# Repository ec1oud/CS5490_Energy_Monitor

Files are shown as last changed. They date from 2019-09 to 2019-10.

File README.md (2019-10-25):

# UEXT AC Energy Monitor module

I'm developing this for use with an 
[Olimex board](https://www.olimex.com/Products/OLinuXino/RT5350F/RT5350F-OLinuXino-EVB/open-source-hardware)
that runs [OpenWrt](https://openwrt.org/toh/olimex/rt5350f-olinuxino-evb) and
has two GPIO-controlled relays, which I'm hoping to use as a pool pump
controller.  I want to be able to monitor the performance of the pool pump over
time, because this summer it started overheating and eventually failed.  It
would be nice to get an early warning when that's about to happen.  I was
searching and it seems that the 
[CS5490](https://www.cirrus.com/products/cs5490/) will fit the bill: it's 3.3V
powered, cheap enough, doesn't require much supporting circuitry, and works
with current transformers.  The little Olimex board ought to be a good
replacement for the old PC with a DS2413 relay connected to a DS9490 USB
adapter, that has been acting as a pool pump timer (and doing some other minor
home automation tasks) for a few years.

So far I have a working breakout board, designed with 
[KiCad](http://kicad-pcb.org/), that is successfully measuring AC current.  It
has a resistive voltage divider for measuring voltage too, but there is a
safety issue: the design requires connecting DC ground to the neutral wire,
while the other end of the voltage divider goes to line voltage.  Usually
embedded systems like this are kept "floating" behind a transformer or isolated
switching power supply.  I would prefer to measure the full 240VAC that the
pool pump runs on, for accurate power computation, but of course I'm not going
to connect the DC ground of this board (and consequently the ground of the
Olimex board) to a "hot" wire.  In either case, the isolation of the Ethernet
port would depend on the fact that (hopefully) the network jack is
transformer-coupled, because I certainly wouldn't want to cause ground loop
issues on the network either.

Measuring current might be good enough to monitor my pool pump (although it's
not satisfying not to get all the measurements this chip is capable of).  But
to really use it as an energy monitor for anything other than 120VAC US-type
circuits, an isolated design is needed.  I'm thinking my options are to let the
entire CS5490 chip run from an independent power supply and use optocouplers to
isolate the serial line, so that the Olimex board can have a floating DC
ground; or, run everything from a plain old step-down transformer, measure the
AC voltage coming from the transformer (before the rectifier), and calibrate
the CS5490 so that it thinks it's measuring the full AC voltage feeding the
transformer.  An AC brownout ought to result in a proportionately lower voltage
from the transformer; and I hope there is no phase difference significant
enough to affect the power computation.

It also turns out the RT5350F-OLinuXino-EVB has a design flaw: the 
[UEXT connector](https://www.olimex.com/Products/Modules/UEXT/) has a serial
port, but it's the same one that the OpenWrt firmware is using for the Linux
console!  So I can't use those serial lines for communicating with external
hardware (which I thought is supposed to be the main purpose of a UEXT
connector) unless I alter the firmware (or at least the kernel boot parameters)
to disable the serial console, which would also amount to "bricking" the board
if anything goes wrong with the network configuration.  But there's another
serial port on the 40-pin EXT4 connector.  So I designed my board to plug into
the UEXT connector, but now I need to redesign it to plug into the 40-pin
connector instead, which makes it less portable to other embedded systems.  And
also take care of the AC isolation problem somehow.

So now you know the caveats... you'd probably better not connect the line and
neutral screw terminals to anything, unless you know what you're doing.  But
measuring current with a current transformer is pretty safe AFAIK, and works
fine with this design.  I wrote a little test GUI with Qt to communicate with
the board using an FTDI adapter or something like that.  I also wrote another
test client using Lua 5.1 on the OpenWrt firmware, but it depends on being able
to use lua-rs232 at 600 baud (the default baud rate of the CS5490's serial
lines).  See 
[the issue about that](https://github.com/openwrt/packages/issues/10024).

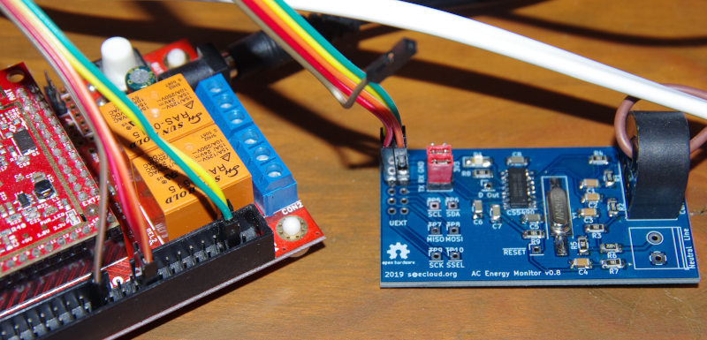
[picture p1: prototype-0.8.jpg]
photo of the prototype so far


A design for a 3D-printable DIN rail mounting solution is also included:

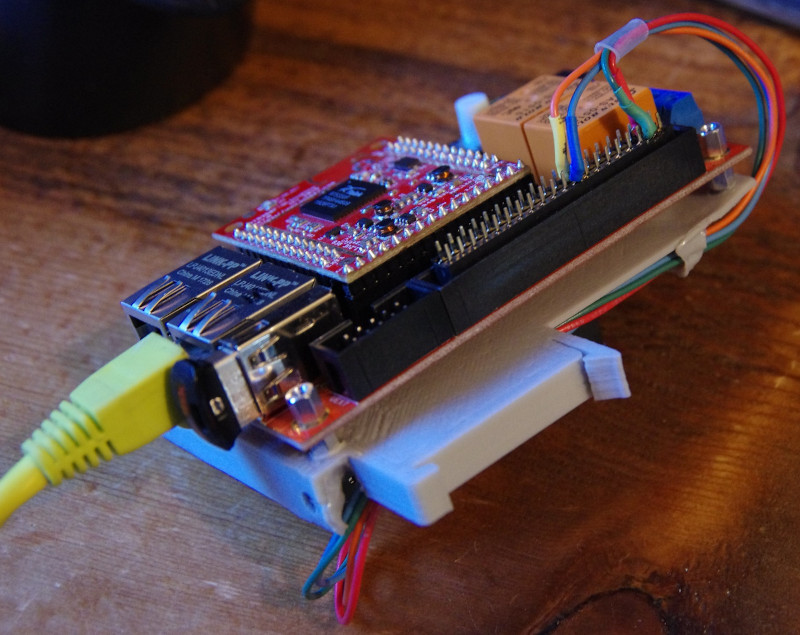
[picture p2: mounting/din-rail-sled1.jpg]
sled for mounting on a DIN rail


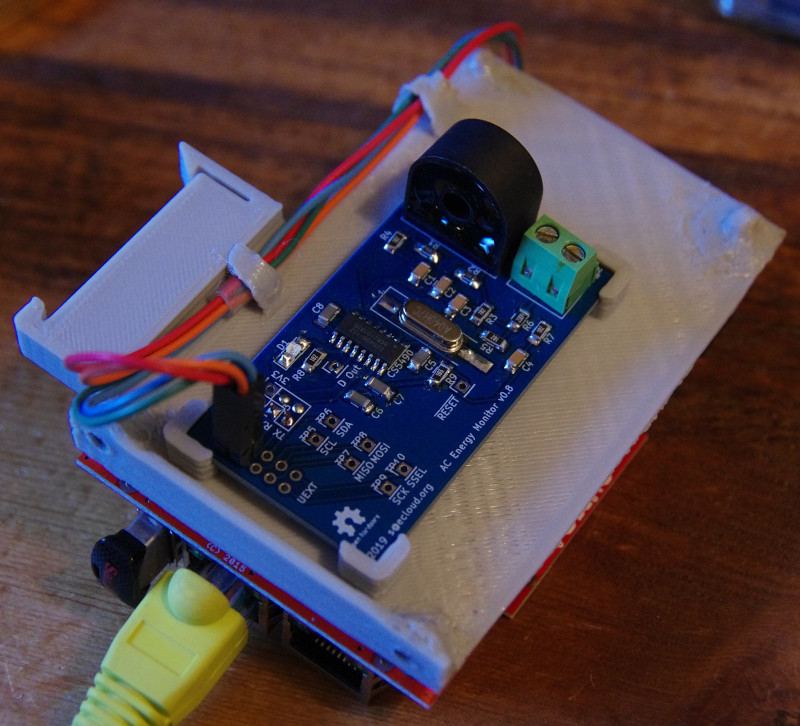
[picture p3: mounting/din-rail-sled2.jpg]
sled for mounting on a DIN rail


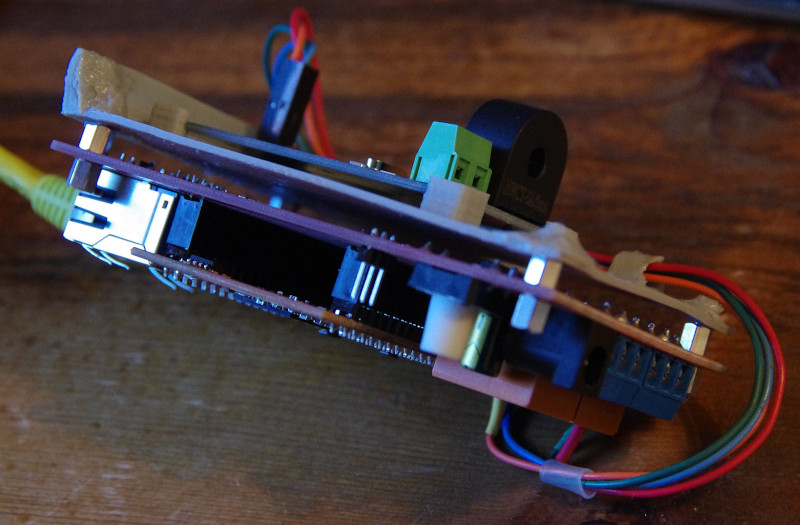
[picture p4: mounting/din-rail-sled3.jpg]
sled for mounting on a DIN rail


The hardware design is licensed under a 


[Creative Commons Attribution-ShareAlike 4.0 International License](http://creativecommons.org/licenses/by-sa/4.0/)
.

The software has a GPLv3 license.

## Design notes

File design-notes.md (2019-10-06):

# Burden Resistors

If one uses a pair of 22Ω resistors for R1 and R2, then for example when
measuring 3.3A RMS with a 1000:1 transformer, the voltage from IIn+ to IIn-
should be 145mV RMS: V = IR, 3.3 / 1000 * 44 = 0.1452.  I measured 140mV with
my voltmeter under such conditions.  The full-scale range is up to 250mV, or
176.78 mV RMS: so with these burden resistors, we won't be able to measure much
more current than that.

So to be able to measure up to 30A for example, it seems the burden resistors
should be 8Ω total, therefore 4Ω each; then 250mV corresponds to 31.25A.  If we
use 3.3Ω instead, we should be able to measure 37.88A peak or 26.78A RMS.

But the CS5490's RMS current register (page 16 address 6) has a range of 0 to
1; so we'll need to calibrate it for a different current range and multiply the
output in the client software.

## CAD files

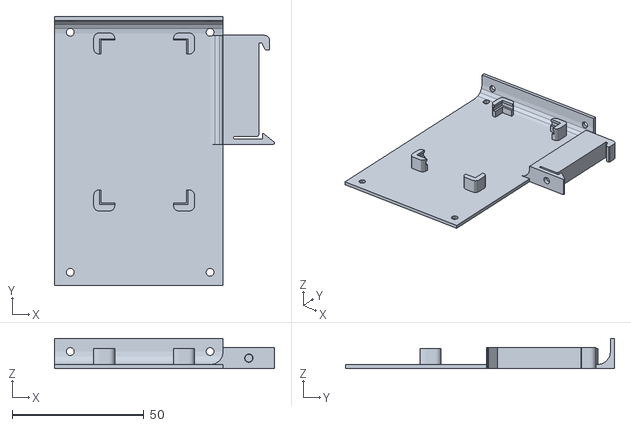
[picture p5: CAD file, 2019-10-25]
mounting/olimex-RT5350F-OLinuXino-EVB-and-CS5490-din-rail-sled.stl
83.5 x 102.0 x 11.5

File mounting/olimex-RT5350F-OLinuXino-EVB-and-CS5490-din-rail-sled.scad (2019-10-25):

// This work is licensed under a Creative Commons Attribution-ShareAlike 3.0 Unported License.
// https://creativecommons.org/licenses/by-sa/3.0/

// board dimensions
boardLength = 102;
boardWidth = 64;
// holes in board
boardWidthStandoffSpacing = 53;
boardHeightStandoffSpacing = 91;

board2dims = [34.25, 63.5, 2];

// DIN rail clamp thickness
clampThickness = 8;
// thickness of sled for board
sledThickness = 1.5;
// the top of the row of PowerPoles will be this far above the DIN rail
heightAboveRail = 10;
// how deep the bolt should go into the solid part, past the spring clip
boltHoleDepth = 10;
// diameter where the bolt passes through the spring clip
looseBoltDiameter = 3.2;
// diameter where the bolt should screw into the DIN holder body
tightBoltDiameter = 2.9;
// standoff dims
standoffDiameter = 8;
standoffScrewHoleDiameter = 3;
standoffHeight = 2.5;

$fn = 16;

// DIN rail clamp
// adapted from Thingiverse 101024 by Robert Hunt
// made with 1mm wider opening: my rail is bigger or my printer prints too small
// Dimensions: 19.74 x 41.355 x clampThickness
module din_clamp() {
	$fn = 24;
	translate([-9.72, -13.1, 0]) mirror([1, 0, 0])
	difference() {
		linear_extrude(height=clampThickness, convexity=5) {
			// imported Robert's DXF to Inkscape, adjusted, then exported via https://github.com/martymcguire/inkscape-openscad-poly
			polygon(points=
				[[-9.731, 16], [5.910, 16], [6.675, 15.848], [7.324, 15.415], [7.758, 14.766], [7.910, 14], [7.910, 10.855],
				[7.764, 10.502], [7.410, 10.355], [6.854, 10.355], [6.320, 10.510], [5.951, 10.925], [4.910, 13.105], [3.910, 13.106],
				[3.910, -21.394], [3.832, -21.783], [3.617, -22.101], [3.299, -22.315], [2.910, -22.394], [-5.372, -22.394], [-5.736, -22.550],
				[-5.852, -22.894], [-5.729, -23.238], [-5.372, -23.394], [5.160, -23.394], [5.160, -21.464], [5.302, -21.239], [5.566, -21.269],
				[9.561, -24.465], [9.730, -24.717], [9.721, -25.021], [9.538, -25.263], [9.249, -25.355], [-9.731, -25.355]]
				, paths=
				[[0, 1, 2, 3, 4, 5, 6, 7, 8, 9, 10, 11, 12, 13, 14, 15, 16, 17, 18, 19, 20, 21, 22, 23, 24, 25, 26, 27, 28, 29, 30, 31, 32, 33, 0]]
			);
		}
		translate([0, -22.5, clampThickness / 2]) {
			rotate([90, 90, 0]) {
				cylinder(h= boltHoleDepth, r = looseBoltDiameter / 2);
			}
		}
		translate([0, -22.5, clampThickness / 2]) {
			rotate([-90, 90, 0]) {
				cylinder(h= boltHoleDepth, r = tightBoltDiameter / 2);
			}
		}
	}
}
// End of DIN clamp by Robert Hunt

module roundCornersCube(x,y,z,r) {
        minkowski() {
                cube([x - 2 * r, y - 2 * r, z], center=true);
                cylinder(r=r, h=0.1);
        }
}

module pegs(dims) {
        radius = 4;
        translate([dims[0] / 2 - 2, dims[1] / 2 - 2, 3])
                roundCornersCube(8, 8, 6, 2, center=true);
        translate([dims[0] / 2 - 2, dims[1] / -2 + 2, 3])
                roundCornersCube(8, 8, 6, 2, center=true);
        translate([dims[0] / -2 + 2, dims[1] / 2 - 2, 3])
                roundCornersCube(8, 8, 6, 2, center=true);
        translate([dims[0] / -2 + 2, dims[1] / -2 + 2, 3])
                roundCornersCube(8, 8, 6, 2, center=true);
}

module boardCutout(dims, extra) {
        translate(extra / 2 + [0, 0, 4])
                cube(dims + extra, center=true);
        translate(extra / 2 + [0, 0, 5])
                cube(dims + extra - [1, 1, -2], center=true);
        translate(extra / 2 + [0, 0, sledThickness])
                cube(dims + extra - [2, 2, -1], center=true);
}

module zFillet(radius, length) {
	difference() {
		cube([radius, radius, length]);
		cylinder(r=radius, h=length);
	}
}

module yFillet(radius, length) {
	translate([radius, 0, radius])
	rotate([-90, 90, 0])
	zFillet(radius, length);
}

module standoffs4(xspacing, yspacing, dx, dy, diam, height) {
	translate([dx, dy, sledThickness]) {
		cylinder(d=diam, h=height);
		translate([xspacing, 0, 0])
			cylinder(d=diam, h=height);
		translate([xspacing, yspacing, 0])
			cylinder(d=diam, h=height);
		translate([0, yspacing, 0])
			cylinder(d=diam, h=height);
	}
}

module clampWithSled(heightAboveRailTop, height, stickOut) {
	sledBottom = heightAboveRailTop - height;
	difference() {
		union() {
			translate([0, sledBottom, 0]) {
				//~ standoffs4(boardWidthStandoffSpacing, boardHeightStandoffSpacing, 5, 5, standoffDiameter, standoffHeight);
				cube([stickOut, height, sledThickness]);
			}
			translate([30, -30, sledThickness])
				pegs(board2dims);
			din_clamp();
			translate([0, -38.5, sledThickness])
				yFillet(5, 41.355);
			translate([0, heightAboveRailTop - sledThickness, sledThickness]) {
				cube([boardWidth, sledThickness, 10]);
				rotate([0, 0, -90])
					yFillet(5, boardWidth);
			}
		}
		translate([0, sledBottom, -5])
			standoffs4(boardWidthStandoffSpacing, boardHeightStandoffSpacing, 5, 5, standoffScrewHoleDiameter, 10);
		translate([30, -30, sledThickness])
			boardCutout(board2dims, [0.25, 0.25, 0]);
		translate([5, heightAboveRailTop + 5, 5 + sledThickness]) rotate([90, 0, 0]) {
			cylinder(d=standoffScrewHoleDiameter, h=10);
			translate([boardWidthStandoffSpacing, 0, 0])
				cylinder(d=standoffScrewHoleDiameter, h=10);
		}
	}
}

mirror([1, 0, 0])
clampWithSled(heightAboveRail, boardLength, boardWidth);

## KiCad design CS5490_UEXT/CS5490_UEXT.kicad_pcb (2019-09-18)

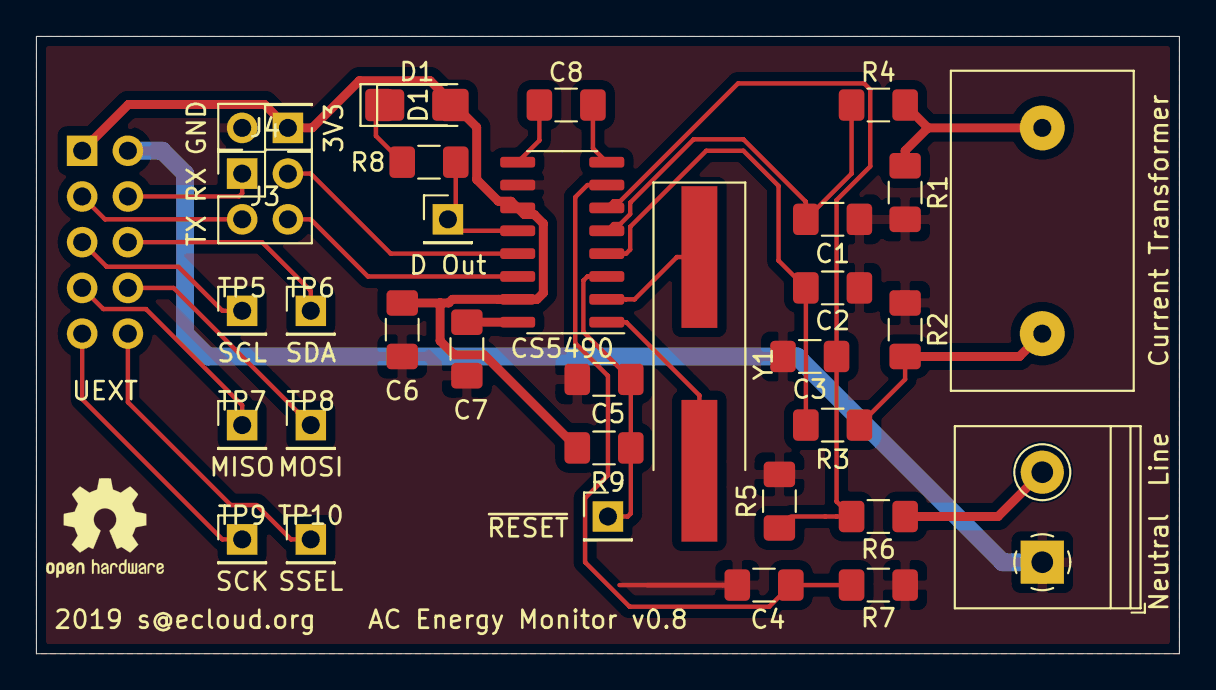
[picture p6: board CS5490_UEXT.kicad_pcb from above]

Board: 2 copper layers, 63.5 x 34.3 mm, 34 parts (1 on the bottom side), 27 nets.

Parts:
C1, C2, C3, C4: 27nF; C_1206_3216Metric_Pad1.42x1.75mm_HandSolder
C5, C6, C7, C8: 100nF; C_1206_3216Metric_Pad1.42x1.75mm_HandSolder
CS5490: CS5490-ISZ; SOIC-16_3.9x9.9mm_P1.27mm
Current Transformer: CT; ct_11.5_mm
D1: LED_1206_3216Metric
D1#2: LED; LED_1806_4516Metric_Pad1.57x1.80mm_HandSolder
D Out: D Out; PinHeader_1x01_P2.54mm_Vertical
J1: BH10S; PinSocket_2x05_P2.54mm_Vertical
J3: serial; PinHeader_2x02_P2.54mm_Vertical
J4: Power; PinHeader_2x01_P2.54mm_Vertical
LOGO1: Logo_Open_Hardware_Small; OSHW-Logo2_7.3x6mm_SilkScreen
Line: Line; TerminalBlock_Philmore_TB132_1x02_P5.00mm_Horizontal
R1, R2: RB/2; R_1206_3216Metric_Pad1.42x1.75mm_HandSolder
R3, R4, R5, R7, R8: 1K; R_1206_3216Metric_Pad1.42x1.75mm_HandSolder
R6: 2M; R_1206_3216Metric_Pad1.42x1.75mm_HandSolder
R9: 10K; R_1206_3216Metric_Pad1.42x1.75mm_HandSolder
TP5: SCL; PinHeader_1x01_P2.54mm_Vertical
TP6: SDA; PinHeader_1x01_P2.54mm_Vertical
TP7: MISO; PinHeader_1x01_P2.54mm_Vertical
TP8: MOSI; PinHeader_1x01_P2.54mm_Vertical
TP9: SCK; PinHeader_1x01_P2.54mm_Vertical
TP10: SSEL; PinHeader_1x01_P2.54mm_Vertical
Y1: 4.096MHz; Crystal_SMD_HC49-SD_HandSoldering

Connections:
+3V3: C6.1, CS5490.11, CS5490.15, D1#2.2, J1.1, J4.1, R9.1
/Line: Line.2, R6.1
/RX: J1.4, J3.1
/TX: J1.3, J3.3
GND: C1.2, C2.1, C3.2, C4.1, C5.1, C6.2, C7.2, CS5490.10, J1.2, J4.2, Line.1, R1.2, R2.1, R5.2, R7.1
unnamed: C1.1, CS5490.5, R4.1
unnamed: C2.2, CS5490.4, R3.1
unnamed: C3.1, CS5490.6, R5.1, R6.2
unnamed: C4.2, CS5490.7, R7.2
unnamed: C5.2, CS5490.3, R9.2
unnamed: C7.1, CS5490.16
unnamed: C8.1, CS5490.9
unnamed: C8.2, CS5490.8
unnamed: D1#2.1, R8.1
unnamed: J1.5, TP5.1
unnamed: J1.6, TP6.1
unnamed: J1.7, TP7.1
unnamed: J1.8, TP8.1
unnamed: J1.9, TP9.1
unnamed: J1.10, TP10.1
unnamed: CS5490.13, J3.2
unnamed: CS5490.14, J3.4
unnamed: Current Transformer.2, R1.1, R4.2
unnamed: Current Transformer.1, R2.2, R3.2
unnamed: CS5490.12, D Out.1, R8.2
unnamed: CS5490.1, Y1.2
unnamed: CS5490.2, Y1.1

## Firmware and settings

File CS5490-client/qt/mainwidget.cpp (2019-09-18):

/****************************************************************************
** This file is part of the CS5490 UEXT energy monitor project hosted at
** github.com/ec1oud/cs5490-uext-energy-monitor
** Copyright (C) 2019 Shawn Rutledge
**
** This file is free software; you can redistribute it and/or
** modify it under the terms of the GNU General Public License
** version 3 as published by the Free Software Foundation
** and appearing in the file LICENSE included in the packaging
** of this file.
**
** This code is distributed in the hope that it will be useful,
** but WITHOUT ANY WARRANTY; without even the implied warranty of
** MERCHANTABILITY or FITNESS FOR A PARTICULAR PURPOSE. See the
** GNU General Public License for more details.
****************************************************************************/
#include "mainwidget.h"
#include "ui_mainwidget.h"
#include <QSerialPortInfo>
#include <QDebug>
#include <QThread>
#include <math.h>

static const QString temperatureFormat = QStringLiteral(u"%1.%2°C");

MainWidget::MainWidget(QWidget *parent) :
    QWidget(parent),
    ui(new Ui::MainWidget)
{
    ui->setupUi(this);
    const auto infos = QSerialPortInfo::availablePorts();
    for (const QSerialPortInfo &info : infos)
        ui->portComboBox->addItem(info.portName());
}

MainWidget::~MainWidget()
{
    delete ui;
}

void MainWidget::on_goButton_clicked()
{
    if (m_serial.portName() != ui->portComboBox->currentText()) {
        m_serial.close();
        m_serial.setPortName(ui->portComboBox->currentText());

        if (!m_serial.open(QIODevice::ReadWrite)) {
            error(tr("Can't open %1, error code %2")
                  .arg(m_serial.portName()).arg(m_serial.error()));
            return;
        }
        if (!m_serial.setBaudRate(600)) {
            error(tr("Can't set baud rate, error code %1")
                  .arg(m_serial.error()));
            return;
        }
    }
    qDebug() << "here goes";
//    sendInstruction(0x01); // reset
//    sendInstruction(0x03); // wake up
//    readRegister(0, 24); // chip status 1
//    readRegister(0, 25); // chip status 2
    uint32_t v = readRegister(16, 27); // temperature
    ui->temperatureValue->setText(temperatureFormat.arg(v >> 16).arg(v & 0xFFFF));
    ui->instCurrentValue->setText(fixedPoint1dot23ToString(readRegister(16, 2)));
    ui->instVoltageValue->setText(fixedPoint1dot23ToString(readRegister(16, 3)));
    ui->instActivePowerValue->setText(fixedPoint1dot23ToString(readRegister(16, 4)));
    ui->activePowerValue->setText(fixedPoint1dot23ToString(readRegister(16, 5)));
    ui->rmsCurrentValue->setText(fixedPoint1dot23ToString(readRegister(16, 6)));
    ui->rmsVoltageValue->setText(fixedPoint1dot23ToString(readRegister(16, 7)));
    ui->reactivePowerValue->setText(fixedPoint1dot23ToString(readRegister(16, 14)));
    ui->peakCurrentValue->setText(fixedPoint1dot23ToString(readRegister(0, 37)));
    ui->peakVoltageValue->setText(fixedPoint1dot23ToString(readRegister(0, 36)));
    ui->apparentPowerValue->setText(fixedPoint1dot23ToString(readRegister(16, 20)));
    ui->powerFactorValue->setText(fixedPoint1dot23ToString(readRegister(16, 21)));
    ui->totalActivePowerValue->setText(fixedPoint1dot23ToString(readRegister(16, 29)));
    ui->totalApparentPowerValue->setText(fixedPoint1dot23ToString(readRegister(16, 30)));
    ui->totalReactivePowerValue->setText(fixedPoint1dot23ToString(readRegister(16, 31)));
    sendInstruction(0x15); // continuous conversion
}

QString MainWidget::fixedPoint1dot23ToString(uint32_t fp)
{
    // https://en.wikipedia.org/wiki/Q_%28number_format%29
    if (fp >> 23)
        fp |= 0xff000000; // sign-extend it from 24 to 32 bits
    double value = double(int(fp)) * exp2(-23);
    return QString::number(value, 'f');
}

uint32_t MainWidget::readRegister(uint8_t page, uint8_t address)
{
    QByteArray sendBuf;
    sendBuf.append(char(page | 0x80));
    sendBuf.append(char(address));
    m_serial.write(sendBuf);

    int polls = 0;
    while (m_serial.bytesAvailable() < 3 && polls < 1000) {
        m_serial.waitForReadyRead(10);
        QCoreApplication::processEvents();
        ++polls;
    }
    qint64 len = m_serial.bytesAvailable();
    QByteArray recvBuf = m_serial.readAll();
    uint32_t ret = 0;
    if (len != 3) {
        error(tr("Expected 3 bytes, got %1").arg(recvBuf.size()));
    } else {
        ret = uint32_t(uint8_t(recvBuf[2]) << 16) + uint32_t(uint8_t(recvBuf[1]) << 8) + uint32_t(recvBuf[0]);
        qDebug() << page << address << "->" << len << recvBuf.toHex() << hex << ret;
    }
    return ret;
}

void MainWidget::sendInstruction(uint8_t i)
{
    QByteArray sendBuf;
    i |= 0xC0; // make it into an Instruction
    qDebug() << hex << i;
    sendBuf.append(char(i));
    m_serial.write(sendBuf);
}

void MainWidget::error(const QString &error)
{
    qWarning() << error;
    ui->textOutput->appendPlainText(error);
}

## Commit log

2019-09-18 version 0.8: working PCB; not sure whether UEXT pinout is correct/useful
    I want to use this with a RTF5350F-OLinuXino-UM; but on the evaluation
    board's UEXT port, the serial RX and TX lines are the same ones used
    for the Linux console in the OpenWRT firmware (also physically wired
    to the 3-pin UART0 port). It's thus not a good choice for connecting
    peripheral devices, because I don't want to disable the serial console
    and risk being unable to access the Linux system, in case anything
    goes wrong with network configuration. But there's another serial port
    on the 40-pin EXT4 connector. That's a better one to use. So maybe
    the next version of this board could have both connectors so that if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
    [CS5490_UEXT-B_Cu.gbr, CS5490_UEXT-B_Mask.gbr, CS5490_UEXT-Edge_Cuts.gbr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]
2019-09-18 Add a Qt Serial Port client GUI for reading values from the CS5490
    Of course the board will be used with embedded systems mainly,
    but I wanted to test it on a PC to make sure it works. Just connect
    to your FTDI or CP2102 usb->serial converter and run this to
    communicate with it at the default 600 baud.
2019-09-28 rearrange kicad project to enable cloning
    [CS5490_UEXT-B_Cu.gbr, CS5490_UEXT-B_Mask.gbr, CS5490_UEXT-Edge_Cuts.gbr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]
2019-10-06 lua client: offset calibration
2019-10-06 refactor lua clients: write cs5490 module; calibration in separate file
2019-10-06 perform current gain calibration with 22Ω burden resistors
2019-10-20 perform current gain calibration with 3.3Ω burden resistors
    With 22Ω we were probably limited to around 800W max. Need to be able
    to measure way more than that, especially for peaks since the pool pump
    is an inductive load. But now it will be less accurate.
2019-10-25 Add a DIN rail sled design for mounting
    [olimex-RT5350F-OLinuXino-EVB-and-CS5490-din-rail-sled.scad, olimex-RT5350F-OLinuXino-EVB-and-CS5490-din-rail-sled.stl]

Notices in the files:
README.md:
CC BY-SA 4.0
